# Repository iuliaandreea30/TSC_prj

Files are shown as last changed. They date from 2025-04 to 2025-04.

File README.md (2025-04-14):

## TSC Project - E-book-Reader

## Diagram
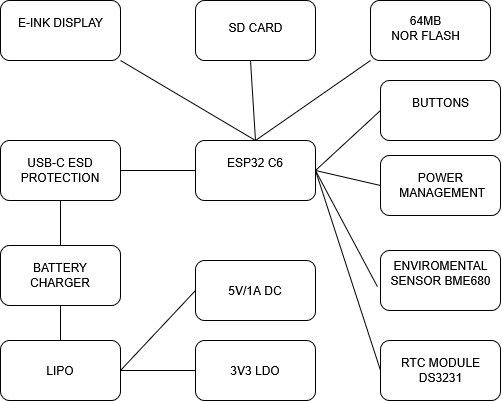
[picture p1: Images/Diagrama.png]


## BOM (Bill Of Materials)

| Component  | Supplier Link | Datasheet |
|---|---|---|
| 112A-TAAR-R03 | [Model](https://store.comet.srl.ro/Catalogue/Product/43497/) | [Datasheet](https://www.snapeda.com/parts/112A-TAAR-R03/Attend/datasheet/) |
| 744043680 | [Model](https://ro.mouser.com/ProductDetail/Wurth-Elektronik/744043680?qs=PGXP4M47uW6VkZq%252BkzjrHA%3D%3D) | [Datasheet](https://www.we-online.com/components/products/datasheet/744043680.pdf) |
| BD5229G-TR | [Model](https://componentsearchengine.com/part-view/BD5229G-TR/ROHM%20Semiconductor) | [Datasheet](https://fscdn.rohm.com/en/products/databook/datasheet/ic/power/voltage_detector/bd52xxg-e.pdf) |
| Capacitor 0402 | [Model](https://ro.mouser.com/c/passive-components/capacitors/ceramic-capacitors/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) | [Datasheet](https://componentsearchengine.com/Datasheets/2/CC0402MRX5R5BB106.pdf) |
| CPH3225A | [Model](https://www.snapeda.com/parts/CPH3225A/Seiko+Instruments/view-part/?ref=snap) | [Datasheet](https://www.snapeda.com/parts/CPH3225A/Seiko%20Instruments/datasheet/) |
| Custom Button | [Model](https://industry.panasonic.com/global/en/products/control/switch/light-touch/number/evqpuj02k) | [Datasheet](https://industry.panasonic.com/global/en/downloads?tab=catalog&small_g_cd=203&part_no=EVQPUJ02K) |
| DS3231SN | [Model](https://www.snapeda.com/parts/DS3231SN%23/Analog+Devices/view-part/?ref=eda) | [Datasheet](https://www.snapeda.com/parts/DS3231SN%23/Analog%20Devices/datasheet/) |
| ESP32 WROVER 0805 Capacitor | [Model]() | [Datasheet]() |
| ESP32 WROVER BME680 Sensor | [Model](https://www.snapeda.com/parts/BME680/Bosch/view-part/?welcome=home) | [Datasheet](https://www.bosch-sensortec.com/media/boschsensortec/downloads/datasheets/bst-bme680-ds001.pdf) |
| ESP32 WROVER MCP73831 Power Management | [Model](https://www.snapeda.com/parts/BME680/Bosch/view-part/?welcome=home) | [Datasheet](https://www.snapeda.com/parts/MCP73831T-2ACI/OT/Microchip/datasheet/) |
| ESP32C6 Varistor 1812 | [Model]() | [Datasheet]() |
| ESP32C6 WROOM-1-N8| [Model](https://www.snapeda.com/parts/ESP32-C6-WROOM-1-N8/Espressif+Systems/view-part/?ref=eda) | [Datasheet](https://www.snapeda.com/parts/ESP32-C6-WROOM-1-N8/Espressif%20Systems/datasheet/) |
| FH34SRJ-24S-0.5SH | [Model](https://ro.mouser.com/ProductDetail/Hirose-Connector/FH34SRJ-24S-0.5SH99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) | [Datasheet](https://www.snapeda.com/parts/FH34SRJ-24S-0.5SH(99)/Hirose%20Connector/datasheet/) |
| LED Chip 0603 | [Model](https://www.snapeda.com/parts/KP-1608SURCK/Kingbright/view-part/?ref=search&t=LED%200603) | [Datasheet](https://www.snapeda.com/parts/KP-1608SURCK/Kingbright/datasheet/) |
| MAX17048G+T10 | [Model](https://www.snapeda.com/parts/MAX17048G+T10/Analog+Devices/view-part/?ref=eda) | [Datasheet](https://www.snapeda.com/parts/MAX17048G+T10/Analog%20Devices/datasheet/) |
| MBR0530 Schottky Diode | [Model](https://www.snapeda.com/parts/MBR0530/Onsemi/view-part/?ref=snap) | [Datasheet](https://www.snapeda.com/parts/MBR0530/ON%20Semiconductor/datasheet/) |
| PGB1010603MR | [Model](https://www.snapeda.com/parts/PGB1010603MR/Littelfuse/view-part/?ref=eda) | [Datasheet](https://www.snapeda.com/parts/PGB1010603MR/Littelfuse%20Inc./datasheet/) |
| QWIIC Connector | [Model](https://www.snapeda.com/parts/PRT-14417/SparkFun/view-part/) | [Datasheet](https://www.snapeda.com/parts/PRT-14417/SparkFun%20Electronics/datasheet/) |
| RCL CPOL 3528 | [Model](https://www.snapeda.com/parts/CPH3225A/Seiko+Instruments/view-part/?ref=eda) | [Datasheet](https://s3.amazonaws.com/snapeda/datasheet/TAJB475K025RNJ_AVX.pdf) |
| Resistor 0402 | [Model](https://grabcad.com/library/resistor-0402-1) | [Datasheet](https://www.yageo.com/upload/media/product/products/datasheet/rchip/PYu-RC_Group_51_RoHS_L_12.pdf) |
| SI1308EDL-T1-GE3 MOSFET | [Model](https://www.snapeda.com/parts/SI1308EDL-T1-GE3/Vishay+Siliconix/view-part/?welcome=home&ref=eda) | [Datasheet](https://www.snapeda.com/parts/SI1308EDL-T1-GE3/Vishay%20Siliconix/datasheet/) |
| SJ | [Model](https://grabcad.com/library/solder-jumpers-1) | [Datasheet]() |
| USB4110-GF-A | [Model](https://componentsearchengine.com/part-view/USB4110-GF-A/GCT%20(GLOBAL%20CONNECTOR%20TECHNOLOGY)) | [Datasheet](https://gct.co/files/drawings/usb4110.pdf) |
| USBLC6-2SC6Y | [Model](https://www.snapeda.com/parts/USBLC6-2SC6Y/STMicroelectronics/view-part/?welcome=home&ref=eda) | [Datasheet](https://www.snapeda.com/parts/USBLC6-2SC6Y/STMicroelectronics/datasheet/) |
| W25Q512JVEIQ | [Model](https://www.snapeda.com/parts/W25Q512JVEIQ/Winbond+Electronics/view-part/?ref=eda) | [Datasheet](https://www.winbond.com/resource-files/W25Q512JV%20SPI%20RevB%2006252019%20KMS.pdf) |
| XC6220A331MR-G | [Model](https://componentsearchengine.com/part-view/XC6220A331MR-G/Torex) | [Datasheet](https://product.torexsemi.com/system/files/series/xc6220.pdf) |
## Detailed Description of Hardware Features

### 1. Microcontroller – ESP32-C6

- **Processor**: 32-bit RISC-V, up to 160MHz clock speed.

- **Memory**: 512KB internal SRAM and 8MB external flash (W25Q512JVEIQ).

- **Connectivity**: Wi-Fi 6 (802.11ax), Bluetooth 5 (LE), USB 2.0 (full-speed).

- **Peripherals**: SPI, I²C, UART, multiple GPIOs.

- **Power Consumption**: Supports low-power modes (sleep, deep sleep).

---

### 2. Environmental Sensor – BME688

- **Measured Parameters**: Temperature, Humidity, Pressure, and Air Quality (VOC/eCO₂).

- **Interface**: I²C at 400kHz (SDA and SCL).

- **Power Consumption**: Very low (~2.1µA in standby, up to a few mA during active measurement).

---

### 3. E-Paper Display (7.5 inch)

- **Model**: Waveshare (or equivalent) with 800×480 resolution.

- **Interface**: 4-wire SPI + control signals (CS, DC, RST, BUSY).

- **Power Consumption**: Very low in static mode (after refresh); requires higher current during refresh (~15–25mA depending on update mode).

---

### 4. Battery and Power Management

- **Battery**: 2500mAh Li-Po (3.7V nominal).

- **Charging IC**: MCP73831 (Microchip) – Li-Po charging via USB-C (up to 1A).

- **Fuel Gauge**: MAX17048 – monitors charge level, voltage, and battery status (I²C).

- **LDO**: XC6220A331MR-G (example) or equivalent, providing a stable 3.3V to the microcontroller and peripherals.

---

### 5. USB-C Port

- **Function**: Battery charging + Data transfer (USB 2.0 full-speed).

- **Protections**: ESD (USBLC6-2SC6Y) + termination resistors.

- **Possibilities**: Firmware updates via USB (bootloader + external tool) or directly via OTA over Wi-Fi.

---

### 6. Buttons (3x Tactile Switches)

- **Type**: Tactile switch (Panasonic or equivalent).

- **Functions**: Menu navigation, option selection, page turn, etc.

- **Connection**: Each button is connected to an ESP32-C6 GPIO, using a debounce circuit (resistor and capacitor) or debounce handled in firmware.

---

### 7. Qwiic Connector (I²C)

- Standard 4-pin connector: VCC, GND, SDA, SCL.

- Allows easy connection of additional I²C sensors or modules (expansion, testing, fast prototyping).

---

### 8. SD Memory Card Connector (112A-TAAR-R03)

- **Function**: External storage for e-books, logs, or firmware updates.

- **Interface**: Can be configured as SD (1-bit / 4-bit) or SPI, depending on firmware configuration.

---

### 9. RTC – DS3231

- **Function**: Provides accurate real-time clock functionality.

- **Interface**: I²C (shared with BME688 and MAX17048).

- **Backup**: Supercapacitor or secondary battery to maintain timekeeping when main power is off.

---

### 10. Additional Memory

- **W25Q512JVEIQ** (External Flash) – connected to ESP32-C6 via dedicated SPI (quad SPI).

  - Used to store firmware and large data (e.g., e-books).

## Power Consumption Summary
| Component | Active (mA) | Sleep (mA) | Notes |
|---|---|---|---|
| ESP32-C6 | ~80–100 | ~0.02 | Depends on Wi-Fi & sleep mode |
| E-Paper Display | ~26 | ~0.01 | Only during refresh |
| BME688 Sensor | ~2.1 | ~0.15 | Sleep mode available |
| RTC DS3231 | ~0.2 | ~0.2 | Constant low power |
| MicroSD Card | ~30–100 | ~0.2 | Depends on access frequency |
| W25Q512JVEIQ Flash| ~10–20 | ~0.01 | During SPI read/write |

## ESP32-C6 Pin Mapping

| ESP32-C6 Pin | Component / Signal | Why? |
|---|---|---|
| GPIO1 | I²C SDA (BME688, MAX17048, DS3231, Qwiic) | Shared I²C line – saves pins and allows easy expansion |
| GPIO2 | I²C SCL (BME688, MAX17048, DS3231, Qwiic) | I²C clock line for all sensors and Qwiic extensions |
| GPIO5 | SPI MISO (E-Paper, External Flash)  | Common SPI data input line |
| GPIO6 | SPI MOSI (E-Paper, External Flash)  | Data output line to e-paper and flash |
| GPIO7 | SPI CLK | Clock signal for the SPI bus |
| GPIO8 | E-Paper CS | Selects the display on the SPI bus |
| GPIO9 | E-Paper DC (Data/Command) | Switches between command and data for the e-paper |
| GPIO10 | E-Paper RST | Hardware reset for the e-paper display |
| GPIO11 | E-Paper BUSY | Status pin (busy/free) from the display |
| GPIO12 | Button #1 | Digital input for page forward navigation |
| GPIO13 | Button #2 | Digital input for page backward navigation |
| GPIO14 | Button #3 | Digital input for selection/option |
| GPIO15 | MAX17048 ALERT (optional) | Low battery level alert pin |
| GPIO16 | USB D+ (internal to USB PHY) | USB 2.0 line (fixed on ESP32-C6) |
| GPIO17 | USB D- (internal to USB PHY) | USB 2.0 line (fixed on ESP32-C6) |
| GPIO18 | Status LED (optional) | Indicator for Wi-Fi activity, charging, notifications |
| GPIO19 | SD Card CS | Chip select for the microSD card (SPI) |
| GPIO20 | SD Card MISO | Data read from microSD card |
| GPIO21 | SD Card MOSI | Data write to microSD card |
| GPIO4 | SD Card CLK | Clock signal for the microSD card (SPI) |

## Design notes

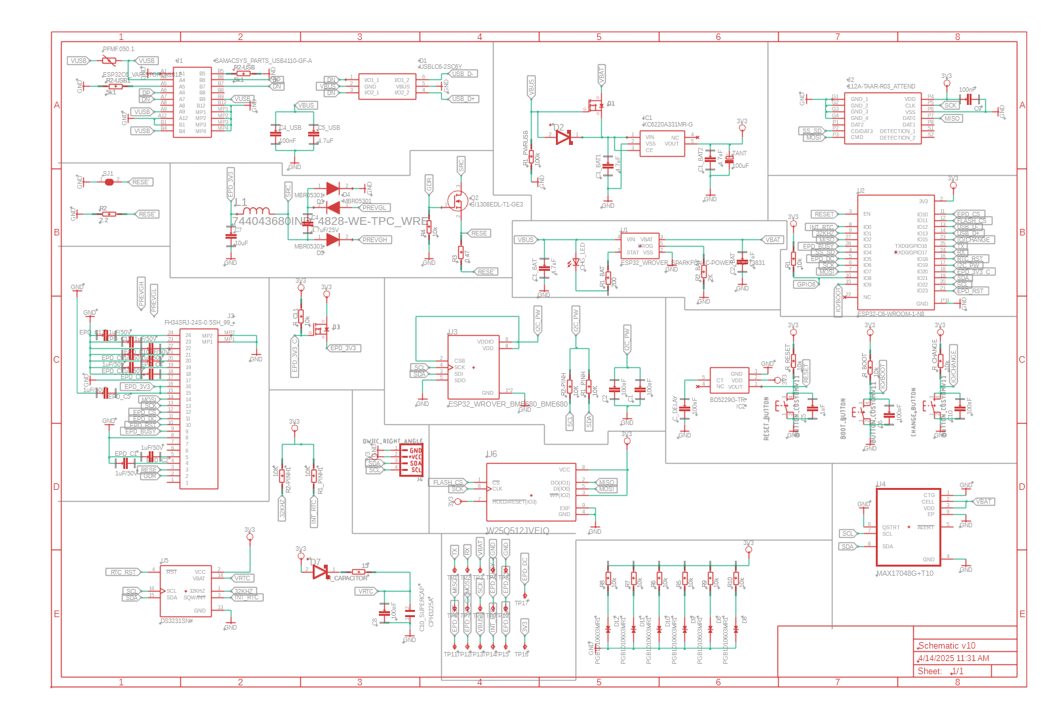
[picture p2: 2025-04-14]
Images/Schematic.png

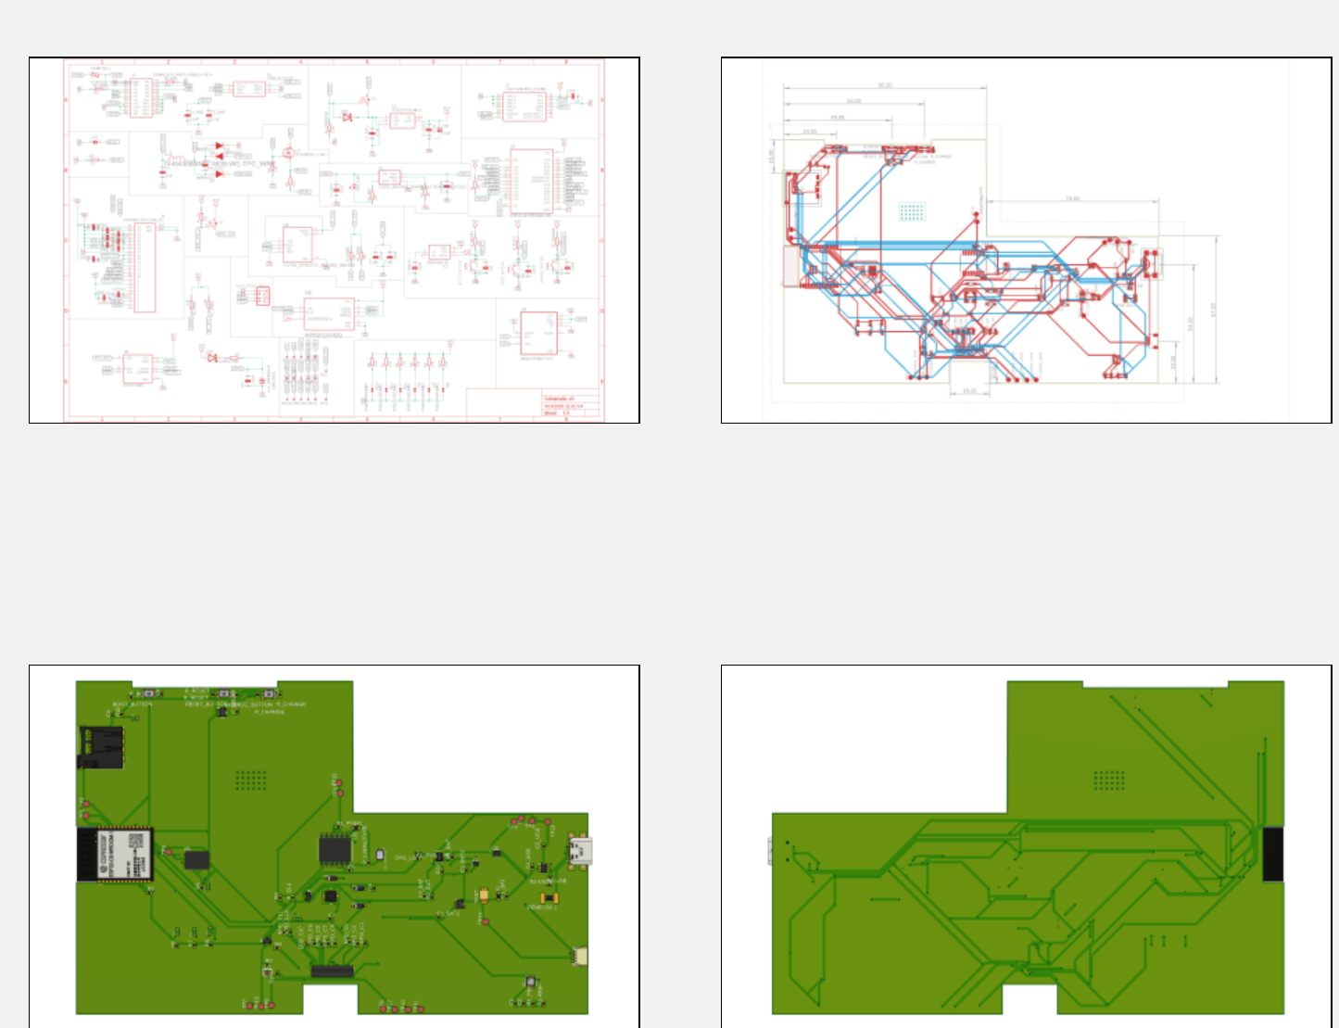
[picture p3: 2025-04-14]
Images/Electronic Design.png

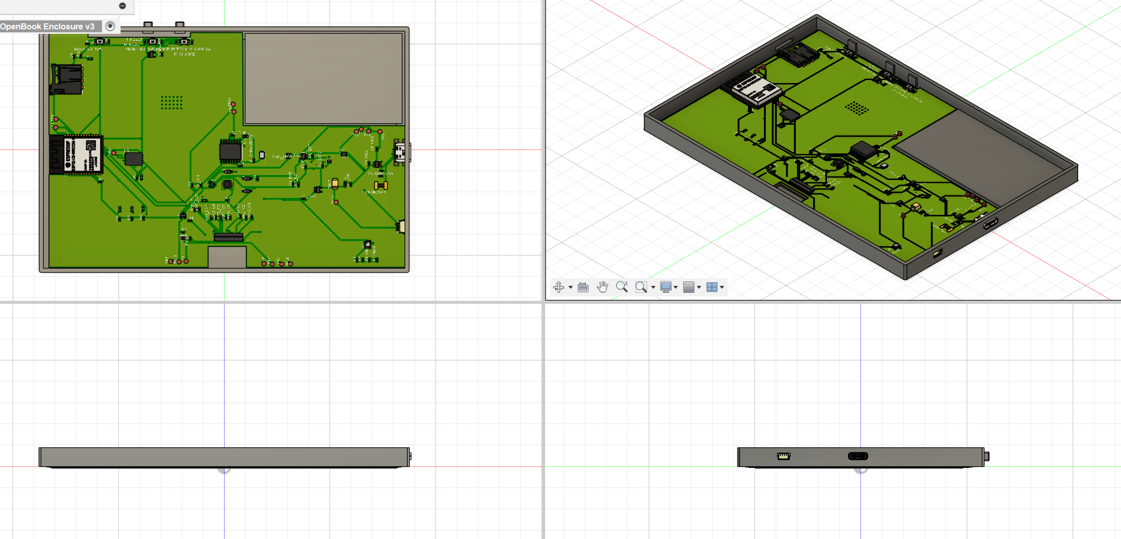
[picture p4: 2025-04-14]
Images/Encased PCB.png

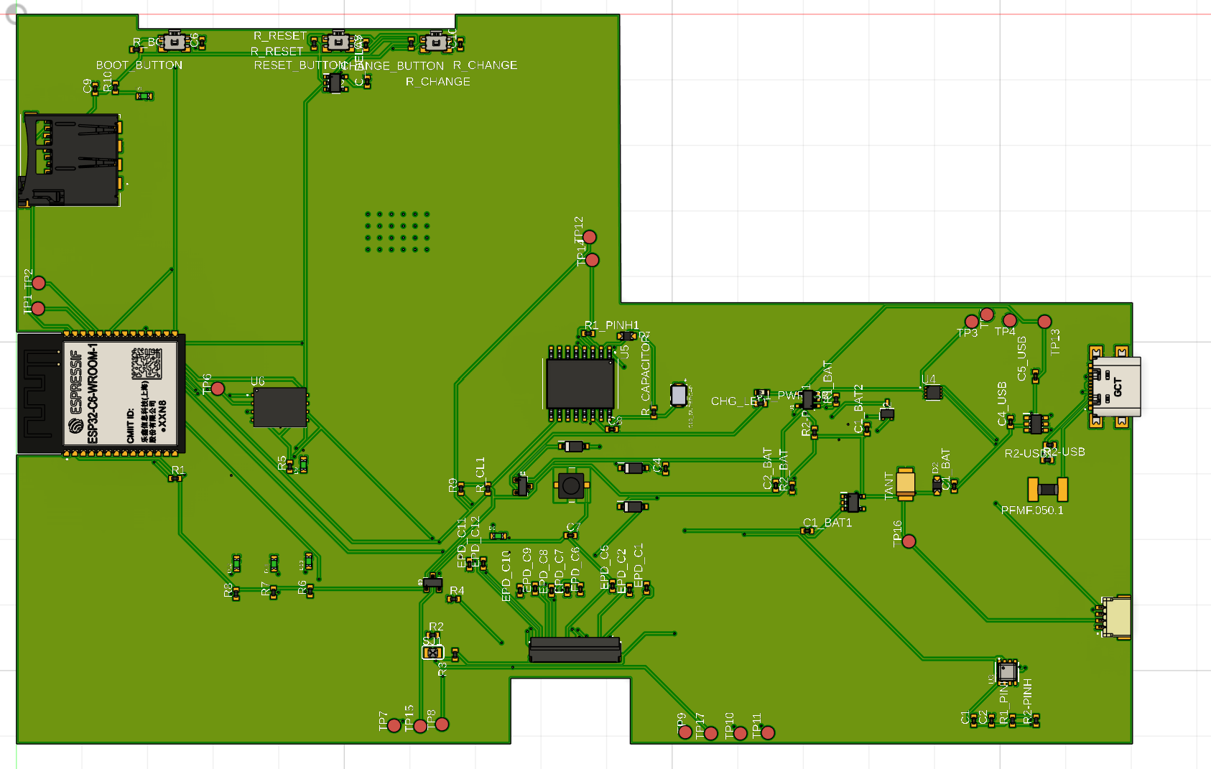
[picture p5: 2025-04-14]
Images/PCB 3D TOP.png

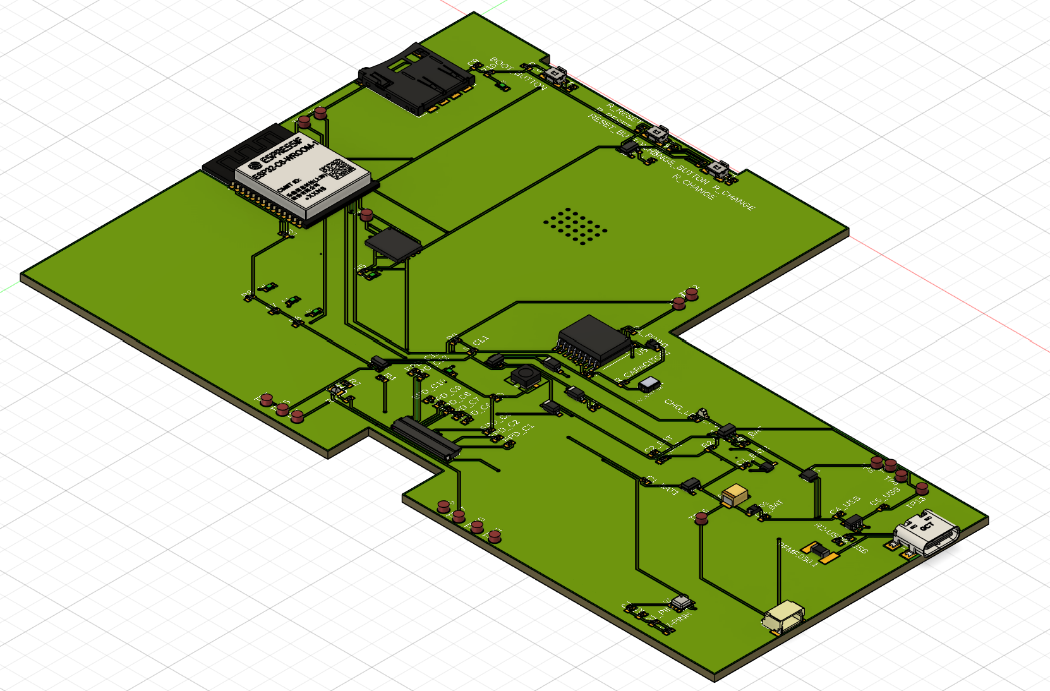
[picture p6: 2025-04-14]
Images/PCB 3D.png

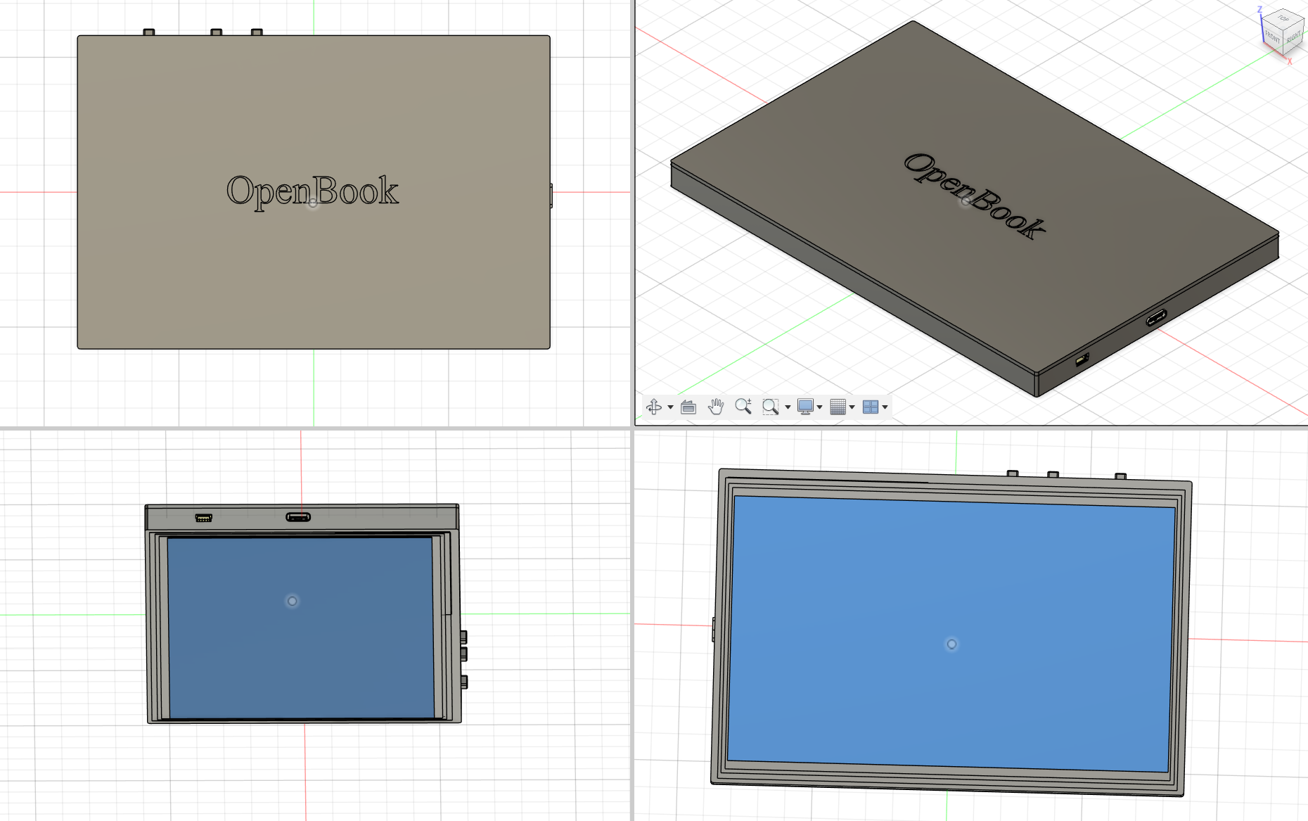
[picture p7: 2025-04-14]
Images/PCB_3D_enclosed.png

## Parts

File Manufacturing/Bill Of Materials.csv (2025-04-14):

Qty | Value | Device | Package | Parts | Description | ARROW_PART_NUMBER | ARROW_PRICE-STOCK | AVAILABILITY | CENTROID_NOT_SPECIFIED | CHECK_PRICES | COPYRIGHT | DATASHEET | DESCRIPTION | DIGIKEY_DESCRIPTION | DIGIKEY_PART_NUMBER | HEIGHT | LEAD_FREE | MANUFACTURER_NAME | MANUFACTURER_PART_NUMBER | MF | MFR_NAME | MOUSER_PART_NUMBER | MOUSER_PRICE-STOCK | MOUSER_TESTING_PART_NUMBER | MOUSER_TESTING_PRICE-STOCK | MP | MPN | PACKAGE | POPULARITY | PREFIX | PRICE | PROD_ID | PURCHASE-URL | ROHS | SNAPEDA_LINK | SPICEPREFIX | TEMPERATURE_RANGE_HIGH | TEMPERATURE_RANGE_LOW | VALUE
1 |  | ADAFRUIT_LEDCHIP-LED0603 | ADAFRUIT_CHIP-LED0603 | CHG_LED | LED
1 |  | SJ | SJ | SJ1 | SMD solder JUMPER |  |  |  |  |  |  |  |  |  |  |  |  |  |  |  |  |  |  |  |  |  |  |  | 3
1 | 0.47 | ESP32_WROVER_EAGLE-LTSPICE_R | ESP32_WROVER_EAGLE-LTSPICE_R0402 | R3 | RESISTOR, European symbol
1 | 100k | ESP32_WROVER_EAGLE-LTSPICE_R | ESP32_WROVER_EAGLE-LTSPICE_R0402 | R1_PWRUSB | RESISTOR, European symbol
8 | 100nF | ESP32_WROVER_EAGLE-LTSPICE_C | ESP32_WROVER_EAGLE-LTSPICE_C0402 | C1, C2, C4_USB, C6, C8, C9, C10, C_DELAY | CAPACITOR, European symbol
1 | 100uF | RCL_CPOL-EUCT3528 | RCL_CT3528 | TANT | POLARIZED CAPACITOR, European symbol |  |  |  |  |  |  |  |  |  |  |  |  |  |  |  |  |  |  |  |  |  |  |  | 0 |  |  |  |  |  |  | C
4 | 10K | ESP32_WROVER_EAGLE-LTSPICE_R | ESP32_WROVER_EAGLE-LTSPICE_R0402 | R1_PINH, R1_PINH1, R2-PINH, R2-PINH1 | RESISTOR, European symbol
12 | 10k | ESP32_WROVER_EAGLE-LTSPICE_R | ESP32_WROVER_EAGLE-LTSPICE_R0402 | R1, R4, R5, R6, R7, R8, R9, R10, R_BOOT, R_CHANGE, R_CL1, R_RESET | RESISTOR, European symbol
1 | 10uF | ESP32_WROVER_EAGLE-LTSPICE_C | ESP32_WROVER_EAGLE-LTSPICE_C0402 | C7 | CAPACITOR, European symbol
1 | 112A-TAAR-R03_ATTEND | 112A-TAAR-R03_ATTEND | 112ATAARR03ATTEND | J2 | Micro SD Card Socket, Push-Push Type, Top Mount, SMT, H=1.83mm, 10u |  |  |  |  |  |  |  | Micro SD Card Socket | Push-Push Type | Top Mount | SMT | H=1.83mm | 10u |  |  | 1.9mm |  | ATTEND | 112A-TAAR-R03 ATTEND
1 | 15 | ESP32_WROVER_EAGLE-LTSPICE_R | ESP32_WROVER_EAGLE-LTSPICE_R0402 | R_CAPACITOR | RESISTOR, European symbol
1 | 1uF | ESP32_WROVER_EAGLE-LTSPICE_C | ESP32_WROVER_EAGLE-LTSPICE_C0402 | C5 | CAPACITOR, European symbol
10 | 1uF/50V | ESP32_WROVER_EAGLE-LTSPICE_C | ESP32_WROVER_EAGLE-LTSPICE_C0402 | EPD_C1, EPD_C2, EPD_C5, EPD_C6, EPD_C7, EPD_C8, EPD_C9, EPD_C10, EPD_C11, EPD_C12 | CAPACITOR, European symbol
1 | 2.2 | ESP32_WROVER_EAGLE-LTSPICE_R | ESP32_WROVER_EAGLE-LTSPICE_R0402 | R2 | RESISTOR, European symbol
1 | 200 | ESP32_WROVER_EAGLE-LTSPICE_R | ESP32_WROVER_EAGLE-LTSPICE_R0402 | R1_BAT | RESISTOR, European symbol
2 | 20V/4.2A/52m?/1.4W | ESP32_WROVER_SPARKFUN-DISCRETESEMI_MOSFET_PCH | ESP32_WROVER_SPARKFUN-DISCRETESEMI_SOT23-3 | Q1, Q3 | P-channel MOSFETs
1 | 2K | ESP32_WROVER_EAGLE-LTSPICE_R | ESP32_WROVER_EAGLE-LTSPICE_R0402 | R2_BAT | RESISTOR, European symbol
5 | 4.7uF | ESP32_WROVER_EAGLE-LTSPICE_C | ESP32_WROVER_EAGLE-LTSPICE_C0402 | C1_BAT, C1_BAT1, C1_BAT2, C2_BAT, C5_USB | CAPACITOR, European symbol
1 | 4.7uF/25V | ESP32_WROVER_EAGLE-LTSPICE_C | ESP32_WROVER_EAGLE-LTSPICE_C0402 | C4 | CAPACITOR, European symbol
2 | 5k1 | ESP32_WROVER_EAGLE-LTSPICE_R | ESP32_WROVER_EAGLE-LTSPICE_R0402 | R2-USB, R2-USB1 | RESISTOR, European symbol
1 | 744043680IND_4828-WE-TPC_WRE | 744043680IND_4828-WE-TPC_WRE | IND_4828-WE-TPC_WRE | L1 |  |  |  |  |  |  | Copyright (C) 2024 Ultra Librarian. All rights reserved. |  |  |  |  |  |  |  | 744043680 |  | Wurth Electronics
1 | BD5229G-TR | BD5229G-TR | SOT95P280X125-5N | IC2 | Voltage Detector with Adjustable Delay Time: CMOS processes are utilized to develop high precision, low current consumption CMOS reset ICs that allow arbitrary setting of the delay time. The extensive lineup includes both Nch Open Drain and CMOS output types in a wide range of detection voltages (from 2.3V to 6.0V, in 0.1V steps), enabling selection of the ideal solution based on customer requirements. In addition, the entire series is of course both lead-free and RoHS-compliant. |  |  |  |  |  |  |  | Voltage Detector with Adjustable Delay Time: CMOS processes are utilized to develop high precision | low current consumption CMOS reset ICs that allow arbitrary setting of the delay time. The extensive lineup includes both Nch Open Drain and CMOS output types in a wide range of detection voltages (from 2.3V to 6.0V | in 0.1V steps) | enabling selection of the ideal solution based on customer requirements. In addition | the entire series is of course both lead-free and RoHS-compliant. |  |  | 1.25mm |  | ROHM Semiconductor | BD5229G-TR |  |  | 755-BD5229G-TR | https://www.mouser.co.uk/ProductDetail/ROHM-Semiconductor/BD5229G-TR?qs=4kLU8WoGk0vvnhrrYwdszw%3D%3D
3 | BUTTON_CUSYOMV11 | BUTTON_CUSYOMV11 | MYBUTTON | BOOT_BUTTON, CHANGE_BUTTON, RESET_BUTTON
1 | CPH3225A | CPH3225A | CAPCP3225X100N | C10_SUPERCAP | Cap 0.011F 3.3V 1210 Flat Check availability |  |  | Not in stock |  | https://www.snapeda.com/parts/CPH3225A/Seiko+Instruments/view-part/?ref=eda |  |  | 11 mF (EDLC) Supercapacitor 3.3 V 1210 (3225 Metric) - - |  |  |  |  |  |  | Seiko Instruments |  |  |  |  |  | CPH3225A |  | 1210 Seiko |  |  | None |  | https://www.snapeda.com/api/url_track_click_mouser/?unipart_id=562593&manufacturer=Seiko Instruments&part_name=CPH3225A&search_term=None |  | https://www.snapeda.com/parts/CPH3225A/Seiko+Instruments/view-part/?ref=snap
1 | DS3231SN# | DS3231SN# | SOIC127P1032X265-16N | U5 | Real Time Clock Serial 16-Pin SOIC W T/R Check availability |  |  | In Stock |  | https://www.snapeda.com/parts/DS3231SN%23/Analog+Devices/view-part/?ref=eda |  |  | Extremely Accurate I2C-Integrated RTC/TCXO/Crystal |  |  |  |  |  |  | Analog Devices |  |  |  |  |  | DS3231SN# |  | SOIC-16 Maxim |  |  | None |  | https://www.snapeda.com/api/url_track_click_mouser/?unipart_id=99048&manufacturer=Analog Devices&part_name=DS3231SN#&search_term=None |  | https://www.snapeda.com/parts/DS3231SN%23/Analog+Devices/view-part/?ref=snap
1 | ESP32-C6-WROOM-1-N8 | ESP32-C6-WROOM-1-N8 | XCVR_ESP32-C6-WROOM-1-N8 | U2 | Check availability |  |  | In Stock |  | https://www.snapeda.com/parts/ESP32-C6-WROOM-1-N8/Espressif+Systems/view-part/?ref=eda |  |  | Multiprotocol Modules ESP32-C6 module | Wi-Fi 6 in 2.4 GHz band | Bluetooth 5 | Zigbee 3.0 and Thread. ESP34-WROOM Compatible - ENGINEERING SAMPLE |  |  |  |  |  |  | Espressif Systems |  |  |  |  |  | ESP32-C6-WROOM-1-N8 |  | None |  |  | None |  |  |  | https://www.snapeda.com/parts/ESP32-C6-WROOM-1-N8/Espressif+Systems/view-part/?ref=snap
1 | ESP32C6_VARISTORCN1812 | ESP32C6_VARISTORCN1812 | ESP32C6_VARISTOR_CT/CN1812 | PFMF.050.1 | VARISTOR |  |  |  |  |  |  |  |  |  |  |  |  |  |  |  |  |  |  |  |  |  |  |  | 0
2 | ESP32_WROVER_AVX---SD0805S020S1R0_AVX_SD0805S020S1R0_0_0AVX_SD0805S020S1R0_0_0 | ESP32_WROVER_AVX---SD0805S020S1R0_AVX_SD0805S020S1R0_0_0AVX_SD0805S020S1R0_0_0 | ESP32_WROVER_AVX---SD0805S020S1R0_AVX_SD0805S020S1R0_0 | D2, D7 | Schottky Barrier Rectifier Diode |  |  |  | No |  |  | http://datasheets.avx.com/schottky.pdf |  | DIODE SCHOTTKY 20V 1A 0805 | 478-7800-1-ND |  | yes |  |  | AVX |  | 581-SD0805S020S1R0 |  |  |  |  |  | 0805 (2012 metric) |  | D |  |  |  | yes |  |  | +125°C | -55°C
1 | ESP32_WROVER_BME680_BME680 | ESP32_WROVER_BME680_BME680 | ESP32_WROVER_BME680_PSON80P300X300X100-8N | U3 | Integrated Environmental Unit |  |  | Unavailable |  |  |  |  | Integrated Environmental Unit |  |  |  |  |  |  | Bosch Sensortec |  |  |  |  |  | BME680 |  | LGA-8 Bosch Tools |  |  | None
1 | ESP32_WROVER_SPARKFUN-IC-POWER_MCP73831 | ESP32_WROVER_SPARKFUN-IC-POWER_MCP73831 | ESP32_WROVER_SPARKFUN-IC-POWER_SOT23-5 | U1 | MCP73831T Li-Ion, Li-Pol Controller |  |  |  |  |  |  |  |  |  |  |  |  |  |  |  |  |  |  |  |  |  |  |  |  |  |  | IC-09995
1 | FH34SRJ-24S-0.5SH_99_ | FH34SRJ-24S-0.5SH_99_ | FH34SRJ24S05SH99 | J3 | (0.50mm) Surface Mount, Right Angle |  |  |  |  |  |  |  | 24 Position FFC | FPC Connector Contacts | (0.50mm) Surface Mount | Right Angle |  |  | 1.1mm |  | Hirose | FH34SRJ-24S-0.5SH(99) |  |  | 798-FH34SRJ24S05SH99 | https://www.mouser.co.uk/ProductDetail/Hirose-Connector/FH34SRJ-24S-0.5SH99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
1 | MAX17048G+T10 | MAX17048G+T10 | SON50P200X200X80-9N | U4 | Check availability |  |  | In Stock |  | https://www.snapeda.com/parts/MAX17048G+T10/Analog+Devices/view-part/?ref=eda |  |  | 3µA 1-Cell/2-Cell Fuel Gauge with ModelGauge |  |  |  |  |  |  | Analog Devices |  |  |  |  |  | MAX17048G+T10 |  | TDFN-8 Maxim |  |  | None |  | https://www.snapeda.com/api/url_track_click_mouser/?unipart_id=329239&manufacturer=Analog Devices&part_name=MAX17048G+T10&search_term=None |  | https://www.snapeda.com/parts/MAX17048G+T10/Analog+Devices/view-part/?ref=snap
3 | MBR05301 | MBR05301 | SOD3716X135N | D3, D4, D5 | ON SEMICONDUCTOR - MBR0530 - DIODE, SCHOTTKY, 0.5A, 30V, SOD-123
6 | PGB1010603MR1 | PGB1010603MR1 | DIOC1608X36N | D6, D8, D9, D10, D11, D12 | Check availability
1 | QWIIC_RIGHT_ANGLE | QWIIC_CONNECTORJS-1MM | JST04_1MM_RA | J4 | SparkFun I2C Standard Qwiic Connector |  |  |  |  |  |  |  |  |  |  |  |  |  |  |  |  |  |  |  |  |  |  |  |  |  |  | CONN-13694 |  |  |  |  |  |  | QWIIC_RIGHT_ANGLE
1 | SAMACSYS_PARTS_USB4110-GF-A | SAMACSYS_PARTS_USB4110-GF-A | SAMACSYS_PARTS_USB4110GFA | J1 | CONN USB 2.0 TYPE-C R/A SMT |  |  |  |  |  |  |  | CONN USB 2.0 TYPE-C R/A SMT |  |  | 3.26mm |  | GCT (GLOBAL CONNECTOR TECHNOLOGY) | USB4110-GF-A |  |  | 640-USB4110-GF-A | https://www.mouser.co.uk/ProductDetail/GCT/USB4110-GF-A?qs=KUoIvG%2F9IlYiZvIXQjyJeA%3D%3D
1 | SI1308EDL-T1-GE3 | SI1308EDL-T1-GE3 | SOT65P210X110-3N | Q2 | MOSFET N-Ch 30V 1.5A TrenchFET SC70 Vishay Si1308EDL-T1-GE3 N-channel MOSFET Transistor, 1.5 A, 30 V, 3-Pin SC-70 |  |  | In Stock |  | https://www.snapeda.com/parts/SI1308EDL-T1-GE3/Vishay+Siliconix/view-part/?ref=eda |  |  | Si1308EDL-T1-GE3 N-channel MOSFET Transistor | 1.5 A | 30 V | 3-Pin SC-70 | Siliconix / Vishay SI1308EDL-T1-GE3 |  |  |  |  |  |  | Vishay Siliconix |  |  |  |  |  | SI1308EDL-T1-GE3 |  | SOT-323 Vishay Semiconductor |  |  | None |  | https://www.snapeda.com/api/url_track_click_mouser/?unipart_id=274603&manufacturer=Vishay Siliconix&part_name=SI1308EDL-T1-GE3&search_term=None |  | https://www.snapeda.com/parts/SI1308EDL-T1-GE3/Vishay+Siliconix/view-part/?ref=snap
17 | TP | TP | TP20R | TP1, TP2, TP3, TP4, TP5, TP6, TP7, TP8, TP9, TP10, TP11, TP12, TP13, TP14, TP15, TP16, TP17 | Test pad
1 | USBLC6-2SC6Y | USBLC6-2SC6Y | SOT95P280X145-6N | D1 | Low Cap. ESD Protection Auto SOT-23-6 STMicroelectronics USBLC6-2SC6Y, Dual Uni-Directional TVS Diode Array, 6-Pin SOT-23 |  |  | In Stock |  | https://www.snapeda.com/parts/USBLC6-2SC6Y/STMicroelectronics/view-part/?ref=eda |  |  | 17V Clamp 5A (8/20µs) Ipp Tvs Diode Surface Mount SOT-23-6 |  |  |  |  |  |  | STMicroelectronics |  |  |  |  |  | USBLC6-2SC6Y |  | SOT-23-6 STMicroelectronics |  |  | None |  |  |  | https://www.snapeda.com/parts/USBLC6-2SC6Y/STMicroelectronics/view-part/?ref=snap
1 | W25Q512JVEIQ | W25Q512JVEIQ | SON127P600X800X80-9N | U6 | Check availability |  |  | In Stock |  | https://www.snapeda.com/parts/W25Q512JVEIQ/Winbond+Electronics/view-part/?ref=eda |  |  | FLASH - NOR Memory IC 512Mb (64M x 8) SPI - Quad I/O 133 MHz 8-WSON (8x6) |  |  |  |  |  |  | Winbond Electronics |  |  |  |  |  | W25Q512JVEIQ |  | Package |  |  | None |  |  |  | https://www.snapeda.com/parts/W25Q512JVEIQ/Winbond+Electronics/view-part/?ref=snap
1 | XC6220A331MR-G | XC6220A331MR-G | SOT95P280X120-5N | IC1 | LDO Voltage Regulators |  |  |  |  |  |  |  | LDO Voltage Regulators |  |  | 1.2mm |  | Torex | XC6220A331MR-G |  |  | 865-XC6220A331MR-G | https://www.mouser.co.uk/ProductDetail/Torex-Semiconductor/XC6220A331MR-G?qs=AsjdqWjXhJ8ZSWznL1J0gg%3D%3D

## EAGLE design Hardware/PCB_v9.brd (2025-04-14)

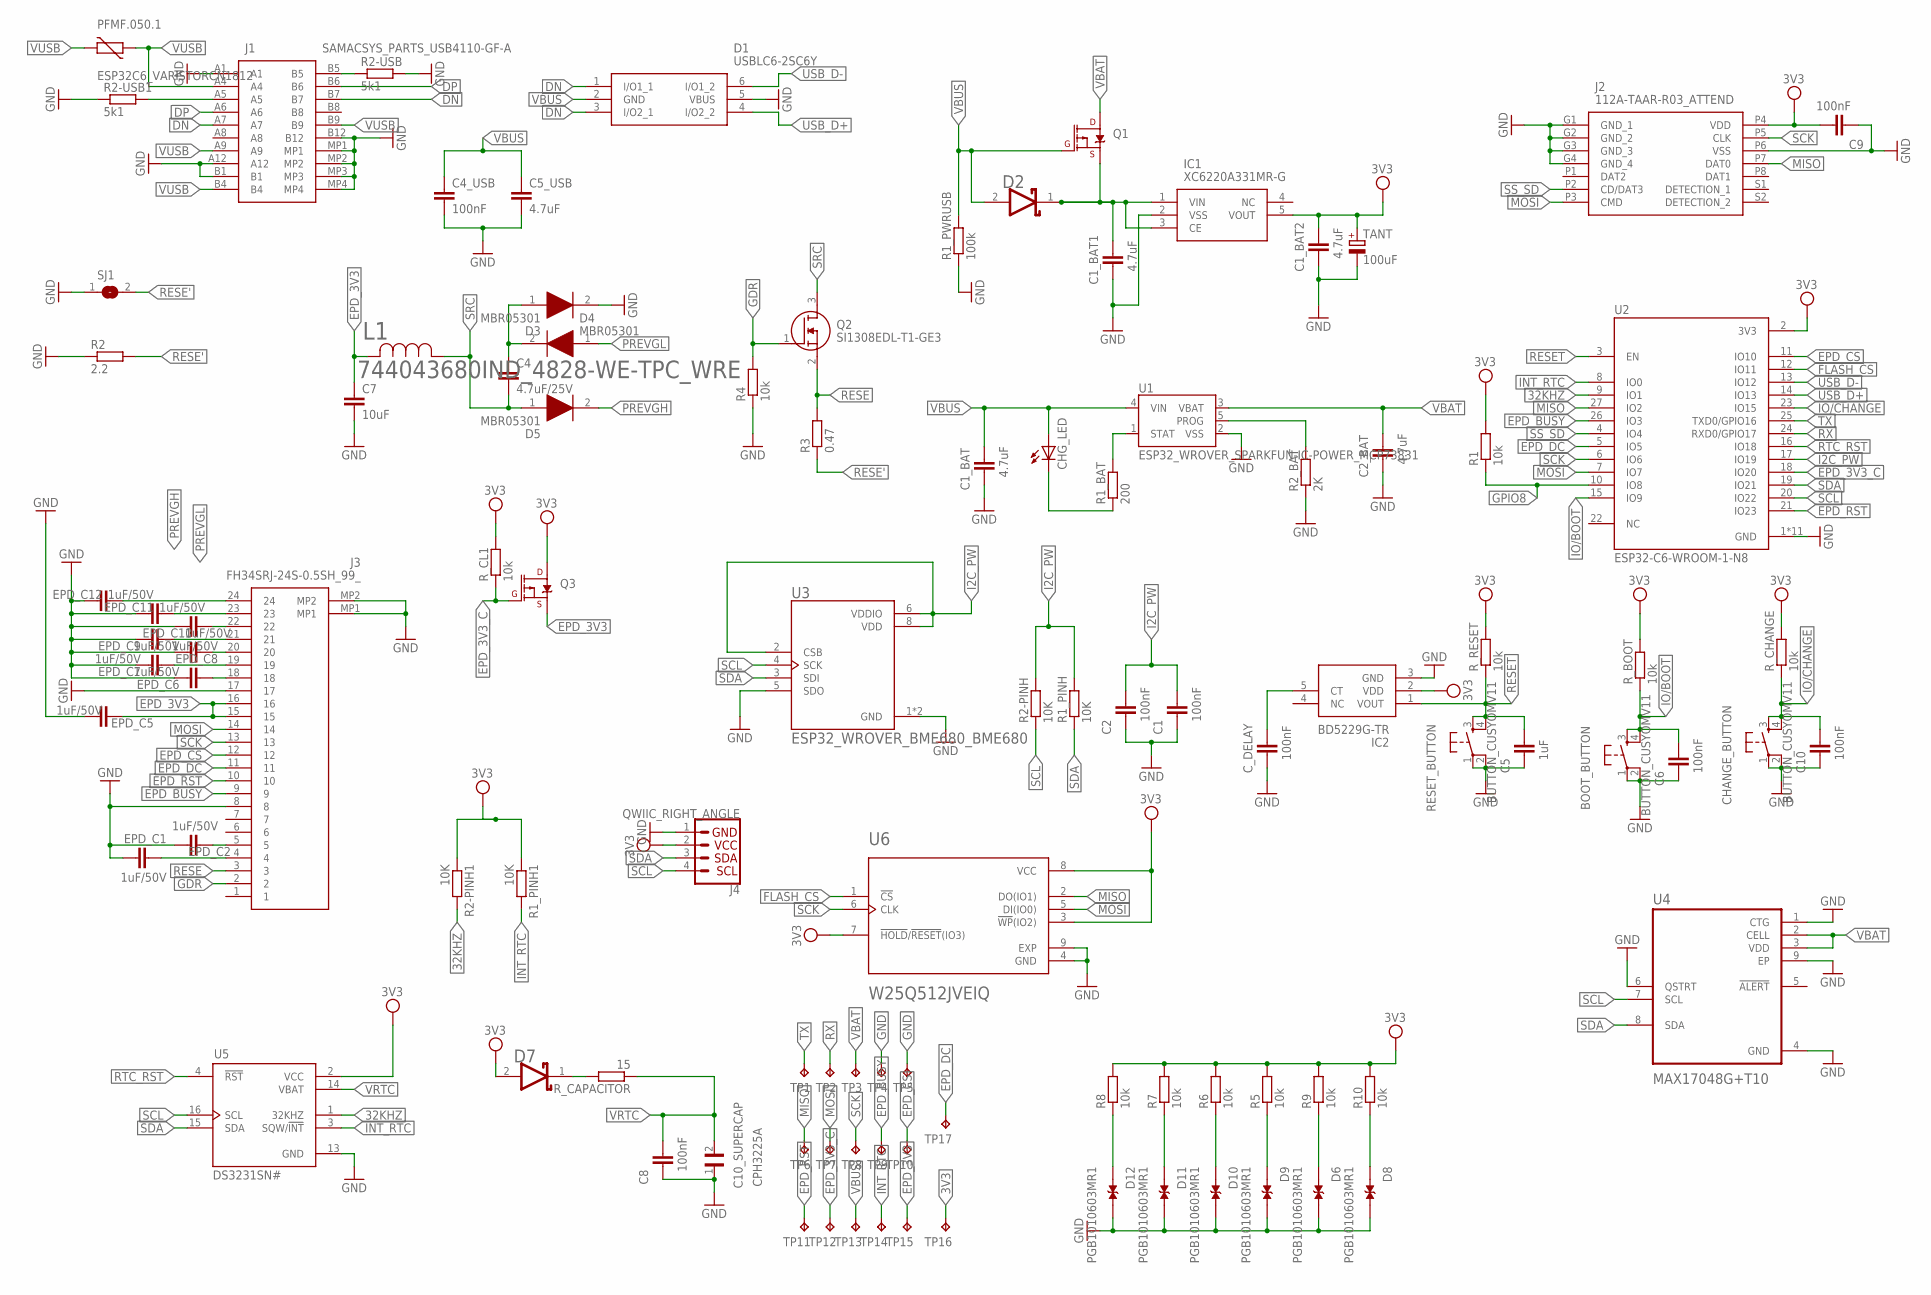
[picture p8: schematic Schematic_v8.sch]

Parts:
BOOT_BUTTON: BUTTON_CUSYOMV11; MYBUTTON
C1, C2, C4_USB, C6, C8, C9, C10: 100nF; ESP32_WROVER_EAGLE-LTSPICE_C0402
C1_BAT, C1_BAT1, C1_BAT2, C2_BAT, C5_USB: 4.7uF; ESP32_WROVER_EAGLE-LTSPICE_C0402
C4: 4.7uF/25V; ESP32_WROVER_EAGLE-LTSPICE_C0402
C5: 1uF; ESP32_WROVER_EAGLE-LTSPICE_C0402
C7: 10uF; ESP32_WROVER_EAGLE-LTSPICE_C0402
C10_SUPERCAP: CPH3225A; CAPCP3225X100N
CHANGE_BUTTON: BUTTON_CUSYOMV11; MYBUTTON
CHG_LED: ADAFRUIT_LEDCHIP-LED0603; ADAFRUIT_CHIP-LED0603
C_DELAY: 100nF; ESP32_WROVER_EAGLE-LTSPICE_C0402
D1: USBLC6-2SC6Y; SOT95P280X145-6N
D2, D7: ESP32_WROVER_AVX---SD0805S020S1R0_AVX_SD0805S020S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; ESP32_WROVER_AVX---SD0805S020S1R0_AVX_SD0805S020S1R0_0
D3, D4, D5: MBR05301; SOD3716X135N
D6, D8, D9, D10, D11, D12: PGB1010603MR1; DIOC1608X36N
EPD_C1, EPD_C2, EPD_C5, EPD_C6, EPD_C7, EPD_C8, EPD_C9, EPD_C10, EPD_C11, EPD_C12: 1uF/50V; ESP32_WROVER_EAGLE-LTSPICE_C0402
IC1: XC6220A331MR-G; SOT95P280X120-5N
IC2: BD5229G-TR; SOT95P280X125-5N
J1: SAMACSYS_PARTS_USB4110-GF-A; SAMACSYS_PARTS_USB4110GFA
J2: 112A-TAAR-R03_ATTEND; 112ATAARR03ATTEND
J3: FH34SRJ-24S-0.5SH_99_; FH34SRJ24S05SH99
J4: QWIIC_RIGHT_ANGLE; JST04_1MM_RA
L1: 744043680IND_4828-WE-TPC_WRE; IND_4828-WE-TPC_WRE
PFMF.050.1: ESP32C6_VARISTORCN1812; ESP32C6_VARISTOR_CT/CN1812
Q1, Q3: 20V/4.2A/52mΩ/1.4W; ESP32_WROVER_SPARKFUN-DISCRETESEMI_SOT23-3
Q2: SI1308EDL-T1-GE3; SOT65P210X110-3N
R1, R4, R5, R6, R7, R8, R9, R10: 10k; ESP32_WROVER_EAGLE-LTSPICE_R0402
R1_BAT: 200; ESP32_WROVER_EAGLE-LTSPICE_R0402
R1_PINH, R1_PINH1, R2-PINH, R2-PINH1: 10K; ESP32_WROVER_EAGLE-LTSPICE_R0402
R1_PWRUSB: 100k; ESP32_WROVER_EAGLE-LTSPICE_R0402
R2: 2.2; ESP32_WROVER_EAGLE-LTSPICE_R0402
R2-USB, R2-USB1: 5k1; ESP32_WROVER_EAGLE-LTSPICE_R0402
R2_BAT: 2K; ESP32_WROVER_EAGLE-LTSPICE_R0402
R3: 0.47; ESP32_WROVER_EAGLE-LTSPICE_R0402
RESET_BUTTON: BUTTON_CUSYOMV11; MYBUTTON
R_BOOT: 10k; ESP32_WROVER_EAGLE-LTSPICE_R0402
R_CAPACITOR: 15; ESP32_WROVER_EAGLE-LTSPICE_R0402
R_CHANGE: 10k; ESP32_WROVER_EAGLE-LTSPICE_R0402
R_CL1: 10k; ESP32_WROVER_EAGLE-LTSPICE_R0402
R_RESET: 10k; ESP32_WROVER_EAGLE-LTSPICE_R0402
SJ1: SJ
TANT: 100uF; RCL_CT3528
TP1, TP2, TP3, TP4, TP5, TP6, TP7, TP8, TP9, TP10, TP11, TP12, TP13, TP14, TP15, TP16, TP17: TP; TP20R
U1: ESP32_WROVER_SPARKFUN-IC-POWER_MCP73831; ESP32_WROVER_SPARKFUN-IC-POWER_SOT23-5
U2: ESP32-C6-WROOM-1-N8; XCVR_ESP32-C6-WROOM-1-N8
U3: ESP32_WROVER_BME680_BME680; ESP32_WROVER_BME680_PSON80P300X300X100-8N
U4: MAX17048G+T10; SON50P200X200X80-9N
U5: DS3231SN#; SOIC127P1032X265-16N
U6: W25Q512JVEIQ; SON127P600X800X80-9N

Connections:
3V3: C1_BAT2.1, C9.1, D7.2 (ANODE), IC1.5 (VOUT), IC2.2 (VDD), J2.P4 (VDD), J4.2, Q3.1 (D), R1.2, R1_PINH1.1, R2-PINH1.1, R5.2, R6.2, R7.2, R8.2, R9.2, R10.2, R_BOOT.2, R_CHANGE.2, R_CL1.2, R_RESET.2, TANT.+, TP16.TP, U2.2 (3V3), U5.2 (VCC), U6.3 (!WP!(IO2)), U6.7 (!HOLD!/!RESET!(IO3)), U6.8 (VCC)
32KHZ: R2-PINH1.2, U2.9 (IO1), U5.1 (32KHZ)
DN: D1.1 (I/O1_1), D1.3 (I/O2_1), J1.A7, J1.B7
DP: J1.A6, J1.B6
EPD_3V3: C7.1, EPD_C5.2, J3.15, J3.16, L1.2, Q3.3 (S), TP15.TP
EPD_3V3_C: Q3.2 (G), R_CL1.1, TP12.TP, U2.18 (IO20)
EPD_BUSY: J3.9, TP9.TP, U2.26 (IO3)
EPD_CS: J3.12, TP10.TP, U2.11 (IO10)
EPD_DC: J3.11, TP17.TP, U2.5 (IO5)
EPD_RST: J3.10, TP11.TP, U2.21 (IO23)
FLASH_CS: U2.12 (IO11), U6.1 (!CS)
GDR: J3.2, Q2.1 (G), R4.2
GND: BOOT_BUTTON.1, BOOT_BUTTON.2, C1.2, C1_BAT.2, C1_BAT1.2, C1_BAT2.2, C2.2, C2_BAT.2, C4_USB.2, C5.2, C5_USB.2, C6.2, C7.2, C8.2, C9.2, C10.2, C10_SUPERCAP.1, CHANGE_BUTTON.1, CHANGE_BUTTON.2, C_DELAY.2, D1.5 (VBUS), D3.2 (K), D6.2, D8.2, D9.2, D10.2, D11.2, D12.2, EPD_C1.1, EPD_C2.1, EPD_C5.1, EPD_C6.1, EPD_C7.1, EPD_C8.1, EPD_C9.1, EPD_C10.1, EPD_C11.1, EPD_C12.1, IC1.2 (VSS), IC2.3 (GND), J1.A1, J1.A12, J1.B1, J1.B12, J1.MP1, J1.MP2, J1.MP3, J1.MP4, J2.G1 (GND_1), J2.G2 (GND_2), J2.G3 (GND_3), J2.G4 (GND_4), J2.P6 (VSS), J3.8, J3.17, J3.MP1, J3.MP2, J4.1, R1_PWRUSB.1, R2.1, R2-USB.2, R2-USB1.1, R2_BAT.1, R4.1, RESET_BUTTON.1, RESET_BUTTON.2, SJ1.1, TANT.-, TP4.TP, TP5.TP, U1.2 (VSS), U2.1 (GND), U2.28 (GND), U2.29_1 (GND), U2.29_2 (GND), U2.29_3 (GND), U2.29_4 (GND), U2.29_5 (GND), U2.29_6 (GND), U2.29_7 (GND), U2.29_8 (GND), U2.29_9 (GND), U3.1 (GND), U3.5 (SDO), U3.7 (GND), U4.1 (CTG), U4.4 (GND), U4.6 (QSTRT), U4.9 (EP), U5.13 (GND), U6.4 (GND), U6.9 (EXP)
GPIO8: R1.1, U2.10 (IO8)
I2C_PW: C1.1, C2.1, R1_PINH.2, R2-PINH.2, U2.17 (IO19), U3.2 (CSB), U3.6 (VDDIO), U3.8 (VDD)
INT_RTC: R1_PINH1.2, TP14.TP, U2.8 (IO0), U5.3 (SQW/!INT)
IO/BOOT: BOOT_BUTTON.3, BOOT_BUTTON.4, C6.1, R_BOOT.1, U2.15 (IO9)
IO/CHANGE: C10.1, CHANGE_BUTTON.3, CHANGE_BUTTON.4, R_CHANGE.1, U2.23 (IO15)
MISO: J2.P7 (DAT0), TP6.TP, U2.27 (IO2), U6.2 (DO(IO1))
MOSI: J2.P3 (CMD), J3.14, TP7.TP, U2.7 (IO7), U6.5 (DI(IO0))
unnamed: C1_BAT1.1, D2.1 (CATHODE), IC1.1 (VIN), IC1.3 (CE), Q1.3 (S)
unnamed: C4.1, D3.1 (A), D4.2 (K)
unnamed: J1.A5, R2-USB1.2
unnamed: R1_BAT.2, U1.1 (STAT)
unnamed: R2_BAT.2, U1.5 (PROG)
unnamed: EPD_C6.2, J3.18
unnamed: EPD_C8.2, J3.20
unnamed: J1.B5, R2-USB.1
unnamed: CHG_LED.C, R1_BAT.1
unnamed: EPD_C1.2, J3.4
unnamed: EPD_C2.2, J3.5
unnamed: EPD_C7.2, J3.19
unnamed: EPD_C10.2, J3.22
unnamed: D7.1 (CATHODE), R_CAPACITOR.2
unnamed: EPD_C12.2, J3.24
unnamed: D12.1, R8.1
unnamed: C_DELAY.1, IC2.5 (CT)
unnamed: D11.1, R7.1
unnamed: D10.1, R6.1
unnamed: D9.1, R5.1
unnamed: D6.1, R9.1
unnamed: D8.1, R10.1
PREVGH: D5.2 (K), EPD_C9.2, J3.21
PREVGL: D4.1 (A), EPD_C11.2, J3.23
RESE: J3.3, Q2.2 (S), R3.2
RESE': R2.2, R3.1, SJ1.2
RESET: C5.1, IC2.1 (VOUT), RESET_BUTTON.3, RESET_BUTTON.4, R_RESET.1, U2.3 (EN)
RTC_RST: U2.16 (IO18), U5.4 (!RST)
RX: TP2.TP, U2.24 (RXD0/GPIO17)
SCK: J2.P5 (CLK), J3.13, TP8.TP, U2.6 (IO6), U6.6 (CLK)
SCL: J4.4, R2-PINH.1, U2.20 (IO22), U3.4 (SCK), U4.7 (SCL), U5.16 (SCL)
SDA: J4.3, R1_PINH.1, U2.19 (IO21), U3.3 (SDI), U4.8 (SDA), U5.15 (SDA)
SRC: C4.2, D5.1 (A), L1.1, Q2.3 (D)
SS_SD: J2.P2 (CD/DAT3), U2.4 (IO4)
TX: TP1.TP, U2.25 (TXD0/GPIO16)
USB_D+: D1.4 (I/O2_2), U2.14 (IO13)
USB_D-: D1.6 (I/O1_2), U2.13 (IO12)
VBAT: C2_BAT.1, Q1.1 (D), TP3.TP, U1.3 (VBAT), U4.2 (CELL), U4.3 (VDD)
VBUS: C1_BAT.1, C4_USB.1, C5_USB.1, CHG_LED.A, D1.2 (GND), D2.2 (ANODE), Q1.2 (G), R1_PWRUSB.2, TP13.TP, U1.4 (VIN)
VRTC: C8.1, C10_SUPERCAP.2, R_CAPACITOR.1, U5.14 (VBAT)
VUSB: J1.A4, J1.A9, J1.B4, J1.B9, PFMF.050.1.1, PFMF.050.1.2

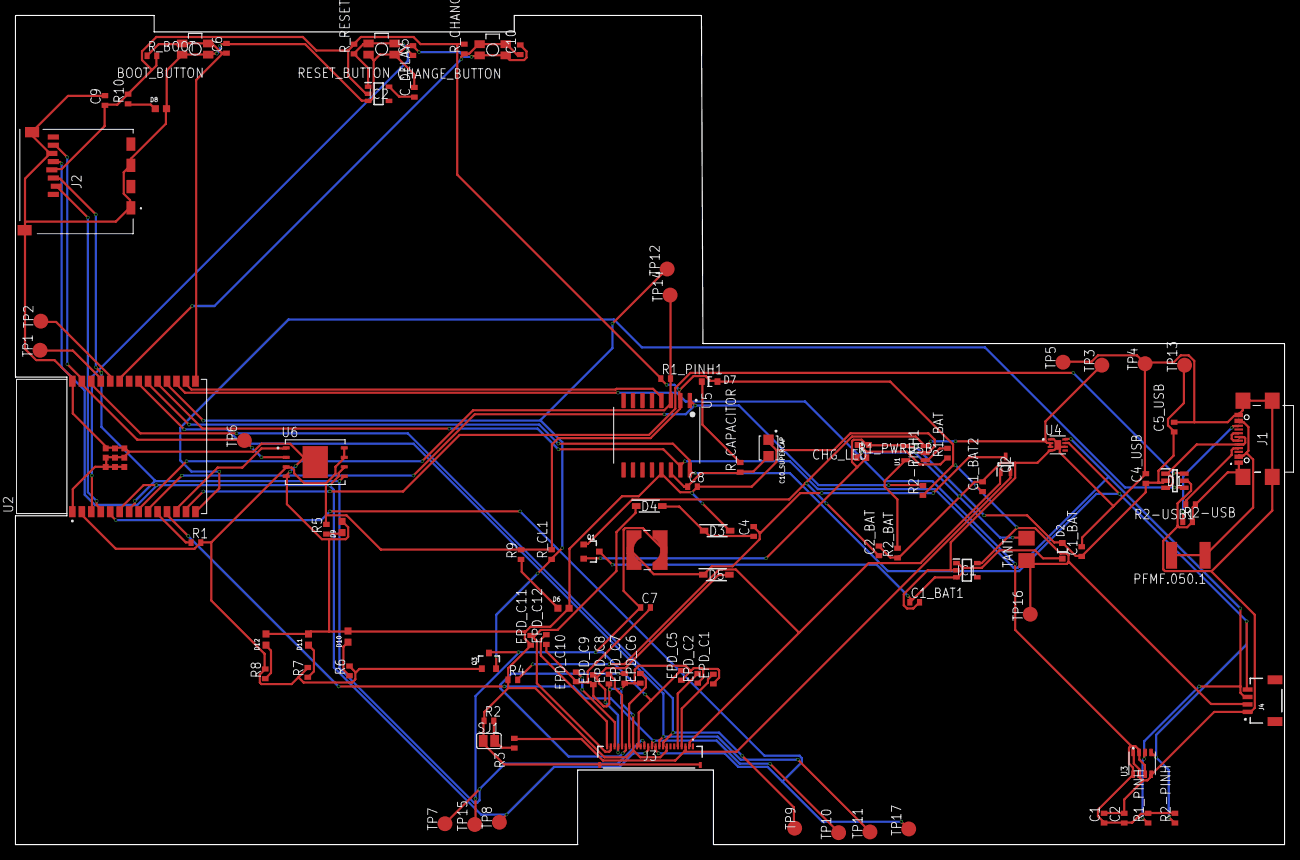
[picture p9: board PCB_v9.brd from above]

Board: 2 copper layers, 170.2 x 111.2 mm, 103 parts (0 on the bottom side), 61 nets.

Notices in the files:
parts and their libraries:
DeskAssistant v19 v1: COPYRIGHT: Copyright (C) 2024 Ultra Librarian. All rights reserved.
